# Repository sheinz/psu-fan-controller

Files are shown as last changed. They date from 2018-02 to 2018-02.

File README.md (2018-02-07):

Power supply fan controller
===========================

Many lab power supplies have annoying fans that spins all the time.
The fan produces noise even though the power supply usually works with small
currents and do not heat up at all. This mod turns on the fan only when
it is needed, when temperature of the heatsink is rising.

## Features

 * Use temperature sensor to gradually increase fan speed
 * Easy configurable temperature and fan speed table
 * Test fan on start-up
 * Uses LM35 temperature sensor

## Schematic

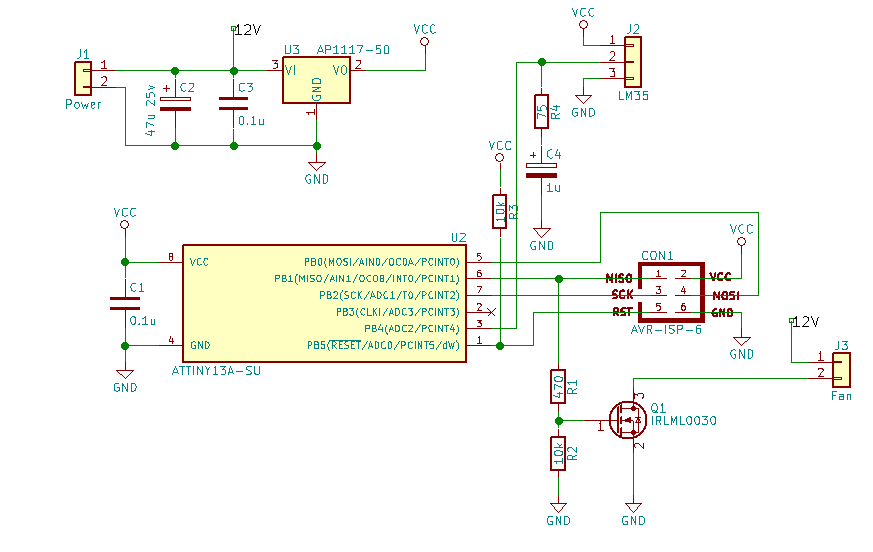
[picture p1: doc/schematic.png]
Schematic


## Licence

MIT

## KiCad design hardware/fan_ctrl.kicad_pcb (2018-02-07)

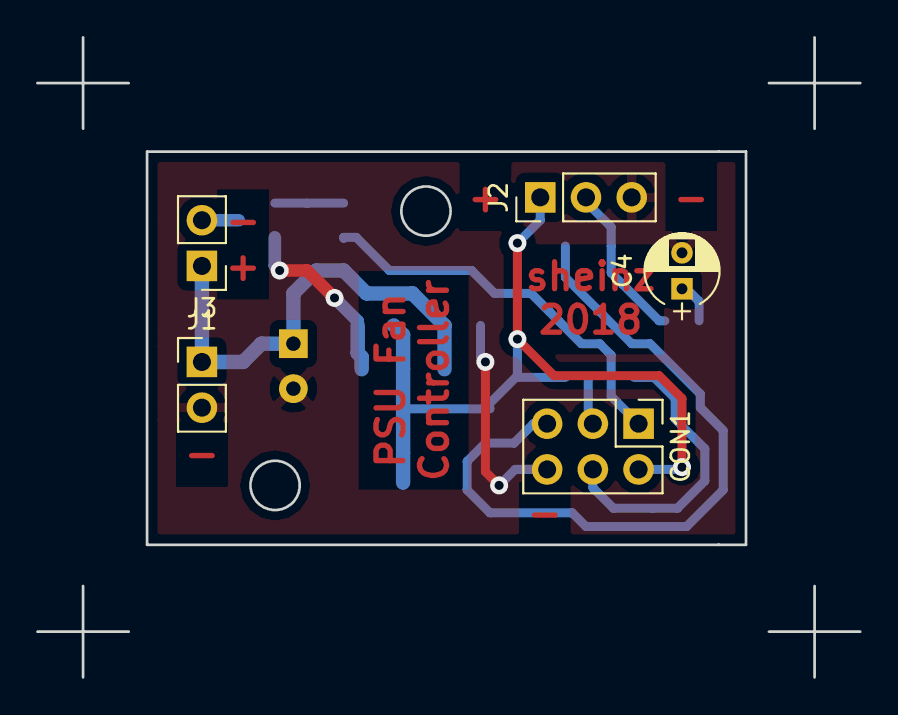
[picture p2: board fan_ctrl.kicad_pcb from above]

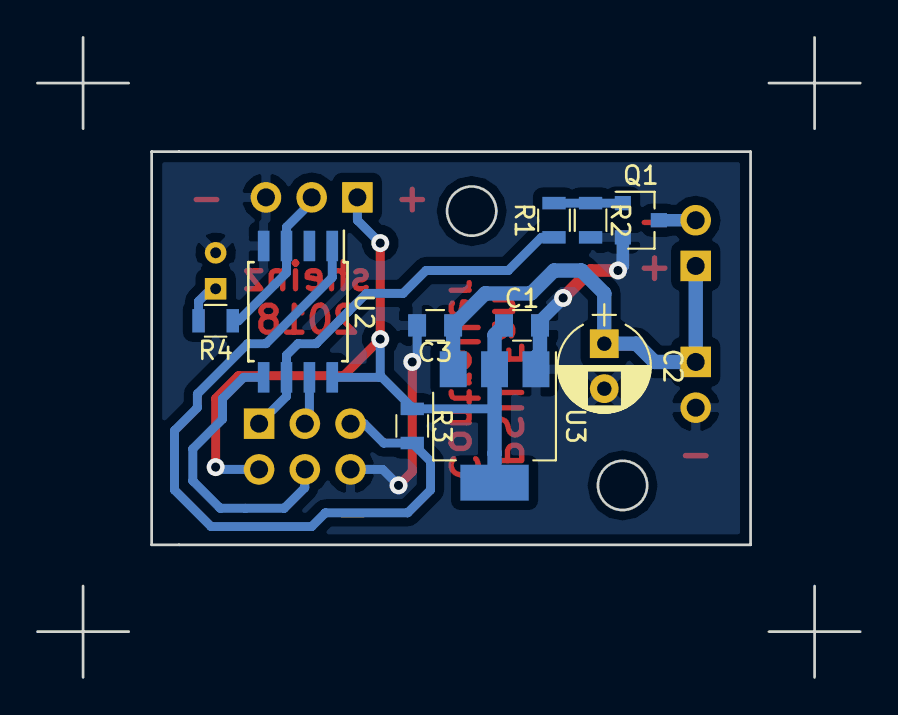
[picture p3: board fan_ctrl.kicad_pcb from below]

Board: 2 copper layers, 33.3 x 21.8 mm, 15 parts (10 on the bottom side), 11 nets.

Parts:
C1, C3: 0.1u; C_0805
C2: 47u 25v; CP_Radial_D5.0mm_P2.50mm
C4: 1u; CP_Radial_D4.0mm_P2.00mm
CON1: AVR-ISP-6; Pin_Header_Straight_2x03_Pitch2.54mm
J1: Power; Pin_Header_Straight_1x02_Pitch2.54mm
J2: LM35; Pin_Header_Straight_1x03_Pitch2.54mm
J3: Fan; Pin_Header_Straight_1x02_Pitch2.54mm
Q1: IRLML0030; SOT-23
R1: 470; R_0805
R2, R3: 10k; R_0805
R4: 75; R_0805
U2: ATTINY13A-SU; SOIJ-8_5.3x5.3mm_Pitch1.27mm
U3: AP1117-50; SOT-223-3_TabPin2

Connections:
/12V: C2.1, C3.1, J1.1, J3.1, U3.3
GND: C1.2, C2.2, C3.2, C4.2, CON1.6, J1.2, J2.3, Q1.2, R2.2, U2.4, U3.1
unnamed: C4.1, R4.2
unnamed: CON1.1, R1.1, U2.6
unnamed: CON1.3, U2.7
unnamed: CON1.4, U2.5
unnamed: CON1.5, R3.2, U2.1
unnamed: J2.2, R4.1, U2.3
unnamed: J3.2, Q1.3
unnamed: Q1.1, R1.2, R2.1
VCC: C1.1, CON1.2, J2.1, R3.1, U2.8, U3.2

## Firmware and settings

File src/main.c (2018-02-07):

#include <inttypes.h>

#include <avr/io.h>
#include <avr/eeprom.h>
#include <util/delay.h>
#include <avr/interrupt.h>
#include <avr/wdt.h>
#include <stdbool.h>

#include "timer.h"
#include "adc.h"

#define TEMP_TO_ADC_VAL(x)   ((x) * 2.33)
#define TEMP_30_C   (70)   // 30 * (256/110)
#define TEMP_35_C   (81)
#define TEMP_40_C   (93)
#define TEMP_45_C   (104)
#define TEMP_50_C   (116)
#define TEMP_60_C   (140)
#define TEMP_70_C   (163)
#define TEMP_80_C   (186)

#define TEMP_HISTEREZIS   (3)

typedef struct {
    uint8_t temp;
    uint8_t fan_speed;
} mode_t;

static mode_t modes[] = {
    {TEMP_40_C, 190u},
    {TEMP_45_C, 210u},
    {TEMP_50_C, 230u},
    {TEMP_70_C, 255u},
    {0, 0}
};

// -1 -- off
static int8_t current_mode = -1;


static void set_mode(int8_t mode_index)
{
    if (mode_index > -1) {
        set_pwm(modes[mode_index].fan_speed);
    } else {
        set_pwm(0);
    }

    current_mode = mode_index;
}

static void process(uint8_t curr_temp)
{
    int8_t highest_mode = -1;
    for (uint8_t i = 0; modes[i].temp != 0; i++) {
        if (curr_temp >= modes[i].temp) {
            highest_mode = i;
        }
    }

    if (highest_mode < current_mode) {
        if (modes[current_mode].temp - curr_temp < TEMP_HISTEREZIS) {
            return;   // do not switch to lower mode if difference is too small
        }
    }
    if (highest_mode != current_mode) {
        set_mode(highest_mode);
    }
}

#define VALUE_BUF_SIZE 8
static uint8_t value_buf[VALUE_BUF_SIZE] = {0};

static uint8_t get_average_adc()
{
    for (uint8_t i = 0; i < VALUE_BUF_SIZE - 1; i++) {
        value_buf[i+1] = value_buf[i];
    }
    value_buf[0] = GET_ADC_VALUE();
    uint16_t sum = 0;
    for (uint8_t i = 0; i < VALUE_BUF_SIZE; i++) {
        sum += value_buf[i];
    }
    return (uint8_t)(sum / VALUE_BUF_SIZE);
}

int main(void)
{
    uint8_t adc_val;
    wdt_enable(WDTO_2S);

    INIT_ADC();

    init_timer();

    MCUCR |= _BV(PUD);  // disable pull-up for all inputs (ADC)

    sei();

    sleep_ms(10);
    set_pwm(0xFF);  // testing fan on start up
    sleep_ms(1000);

    set_pwm(0);    // initial state fan is off

    while (1) {
        adc_val = get_average_adc();
        process(adc_val);

        sleep_ms(200);
        wdt_reset();
    }

    return 0;
}

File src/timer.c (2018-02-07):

#include "timer.h"

#include <avr/io.h>

#include <avr/interrupt.h>

static volatile uint32_t sys_ticks;
static volatile uint8_t sub_ticks;

ISR(TIM0_OVF_vect)
{
    sub_ticks++;
    if (sub_ticks == 36) {
        sys_ticks += 2;
        sub_ticks = 0;
    }
}

void init_timer(void)
{
   // Set OC0B pin to output
   PORTB |= ~_BV(PB1);    // pull it high before switching to output
   DDRB |= _BV(PB1);

   // Clear OC0B on Compare Match, set OC0A at TOP (inverted mode)
   // Inverted mode is used in order to remove narrow spikes in OFF mode.
   // Fast PWM mode
   TCCR0A = _BV(COM0B1) | _BV(WGM00) | _BV(WGM01);

   OCR0A = 0xFF;     // initial state OFF (inverted)

   // no prescaling
   TCCR0B = _BV(CS00);

   sys_ticks = 0;
   sub_ticks = 0;

   TIMSK0 = _BV(TOIE0);
}

void set_pwm(uint8_t duty)
{
    if (duty == 0) {
        TCCR0A &= ~_BV(COM0B1);  // disconnect OC0B
        PORTB &= ~_BV(PB0);
    } else {
        TCCR0A |= _BV(COM0B1);  // connect OC0B
        OCR0B = duty;
    }
}

uint32_t get_ticks(void)
{
   uint32_t mseconds;
   uint8_t sreg = SREG;

   cli();

   mseconds = sys_ticks;

   SREG = sreg;

   return mseconds;
}

void sleep_ms(uint32_t mseconds)
{
   uint32_t startTime = get_ticks();

   while ( (startTime + mseconds) > get_ticks() );
}
